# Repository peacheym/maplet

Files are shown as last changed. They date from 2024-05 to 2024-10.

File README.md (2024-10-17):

# Maplet

An ESP32 based eurorack module for libmapper connectivity.

## Why mappings in Eurorack?

Eurorack systems are excellent at making "generative music", where the system plays itself using sequencers, LFOs, clocks, and other modules. That said, there is lacking a method for "performative interaction" with Eurorack (asides from simply adjusting knobs directly on the system).

## Hardware

Maplet's front panel features a simple initial design.

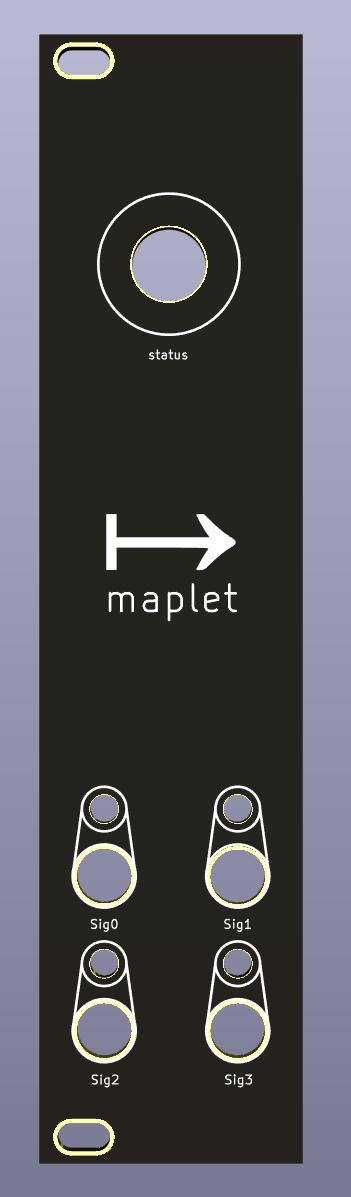
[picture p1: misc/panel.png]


## System Overview

The module uses an [UnexpectedMaker TinyPico](https://www.tinypico.com/) board based on the ESP32 chip as well as a MCP4728 digital-to-analog converter (DAC) as the main components.

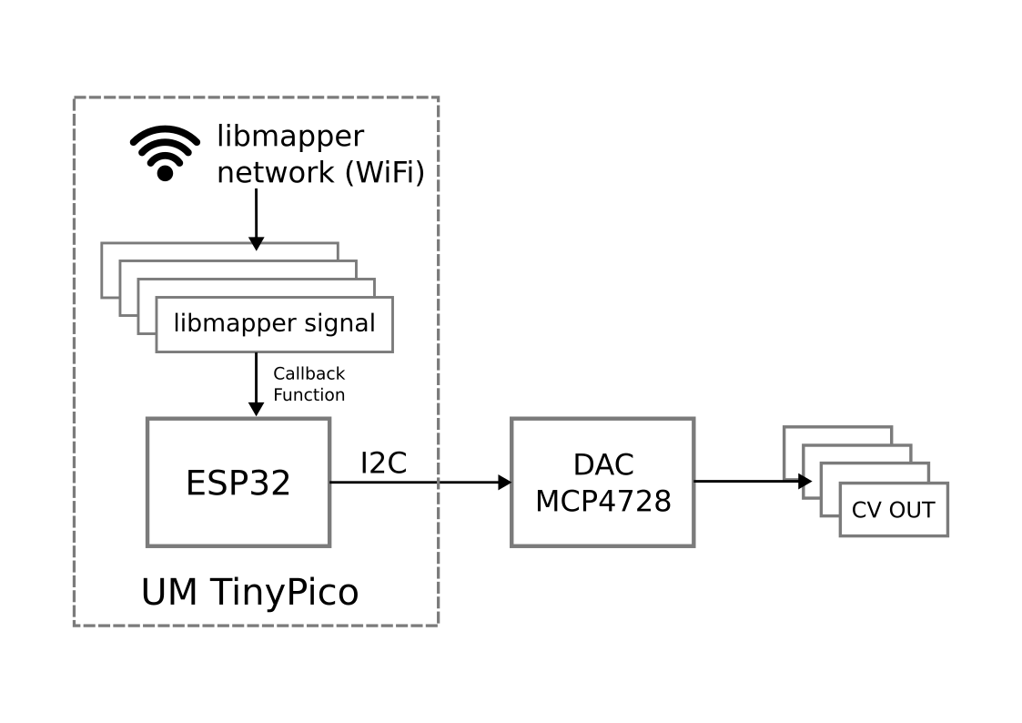
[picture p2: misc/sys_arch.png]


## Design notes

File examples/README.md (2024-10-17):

# Maplet Example | Mapping Hand Tracking to Eurorack Parameters

Maplet has many different use cases in the Eurorack ecosystem. Here's just one example!

pinch-demo

In this example, we show how to create a mapping between a machine-learning based hand-tracking system to parameters of a Eurorack macro-oscillator using the Maplet module.

## MediaPipe: Hands

[MediaPipe](https://github.com/google-ai-edge/mediapipe) is an open-source project maintained by Google that specializes on integrating machine learning with live-streaming data.

One such solution is MediaPipe: Hands that enables 3-dimensional multi-landmark hand-tracking using commodity web-camera. We've previously integrated a libmapper binding to MediaPipe hands ([avaliable here](https://github.com/peacheym/mp-hands-libmapper)) that exposes various hand-tracking landmarks as libmapper signals.

## Defining Mappings

With both the MediaPipe Hands software as well as the Maplet module up and running, we are able to begin creating mappings between them. Using a libmapper session manager such as [Webmapper](https://github.com/libmapper/webmapper/) or [umapper](https://github.com/libmapper/umapper), we can begin by creating a simple direct mapping between signals.

### Direct Mapping

For instance, creating a mapping between the `index-tip` signal and a channel on Maplet (which can be connected to a CV in for pitch-parameter on another eurorack module) results in a theremin type instrument, where the location of your finger-tip along the x-axis is directly mapped to the pitch of the oscilator.

### Convergent Mapping

Though direct mappings can be powerful tools for creating interactions with Digital Musical Insturments and other multimedia systems, there are other types of mapping topologies that libmapper also supports. For instance, a convergent mapping enables two (or more) outgoing signals to influence the value that is received by an incoming signal across the map. This is demonstrated in the main figure above, where both `index-tip` and `thumb-tip` signals are mapped to a channel of the Maplet module. 

```
y=(x$1-x$0).norm() * 4098;
```

Using a mapping-expression (which defines the exact relationship between data signals) we can measure the distance (in any number of avaliable dimensions) between finger-tips and use that result to emulate a pinch gesture. Thus, we can map the _amount of pinch_ to another CV controlled parameter (such as filter-cutoff for example) of a Eurorack module.

## Other examples.

While these initial examples show the basics of how to use the Maplet module as part of the libmapper workflow, we encourage all uers to try it out with their own systems. Feel free to get in touch with any questions or to show any interesting examples that you've come up with!

## Resources

- libmapper website | [link](https://libmapper.org)
- libmapper repo | [link](https://github.com/libmapper/libmapper)
- libmapper tutorials | [link](http://libmapper.github.io/tutorials/introduction.html)
- libmapper expression engine syntax guide | [link](https://github.com/libmapper/libmapper/blob/main/doc/expression_syntax.md)

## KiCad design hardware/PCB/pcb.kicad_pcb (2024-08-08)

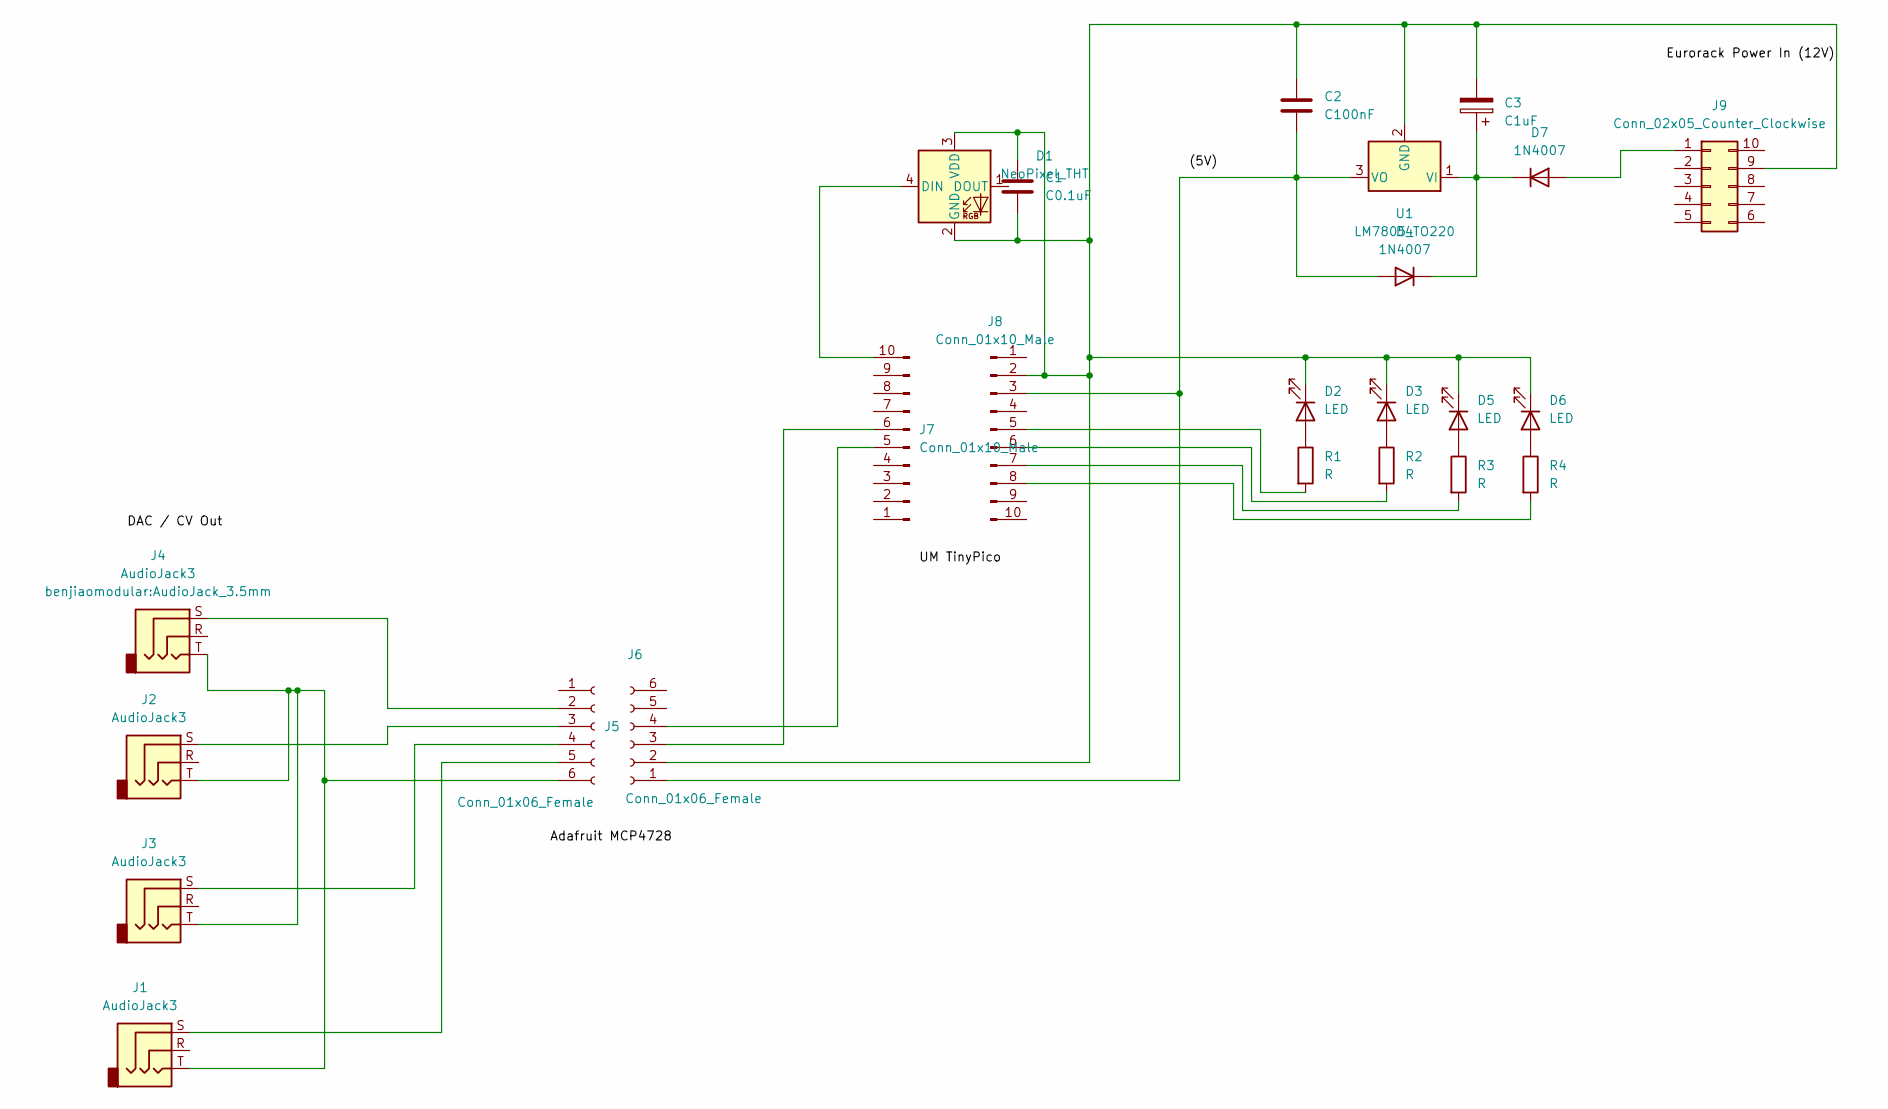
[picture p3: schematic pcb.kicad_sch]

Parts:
C1: C0.1uF; C_Rect_L4.0mm_W2.5mm_P2.50mm
C2: C100nF; C_Rect_L4.0mm_W2.5mm_P2.50mm
C3: C1uF; CP_Radial_D5.0mm_P2.50mm
D1: NeoPixel_THT; LED_D5.0mm-4_RGB_Staggered_Pins
D2, D3, D5, D6: LED; LED_D3.0mm
D4, D7: 1N4007; D_DO-41_SOD81_P10.16mm_Horizontal
J1, J2, J3, J4: AudioJack3; AudioJack_3.5mm
J5, J6: Conn_01x06_Female; PinSocket_1x06_P2.54mm_Vertical
J7, J8: Conn_01x10_Male; PinSocket_1x10_P2.54mm_Vertical
J9: Conn_02x05_Counter_Clockwise; IDC-Header_2x05_P2.54mm_Vertical
R1, R2, R3, R4: R; R_Axial_DIN0204_L3.6mm_D1.6mm_P2.54mm_Vertical
U1: LM7805_TO220; TO-220-3_Vertical

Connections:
unnamed: C1.1, C1.2, C2.1, C3.2, D1.2 (GND), D1.3 (VDD), D2.1 (K), D3.1 (K), D5.1 (K), D6.1 (K), J6.2, J8.2, J9.9, U1.2 (GND)
unnamed: C2.2, D4.2 (A), J6.1, J8.3, U1.3 (VO)
unnamed: C3.1, D4.1 (K), D7.1 (K), U1.1 (VI)
unnamed: D1.4 (DIN), J7.10
unnamed: D2.2 (A), R1.1
unnamed: D3.2 (A), R2.1
unnamed: D5.2 (A), R3.1
unnamed: D6.2 (A), R4.1
unnamed: D7.2 (A), J9.1
unnamed: J1.S, J5.5
unnamed: J2.S, J5.3
unnamed: J3.S, J5.4
unnamed: J4.S, J5.2
unnamed: J1.T, J2.T, J3.T, J4.T, J5.6
unnamed: J6.3, J7.6
unnamed: J6.4, J7.5
unnamed: J8.5, R1.2
unnamed: J8.6, R2.2
unnamed: J8.7, R3.2
unnamed: J8.8, R4.2

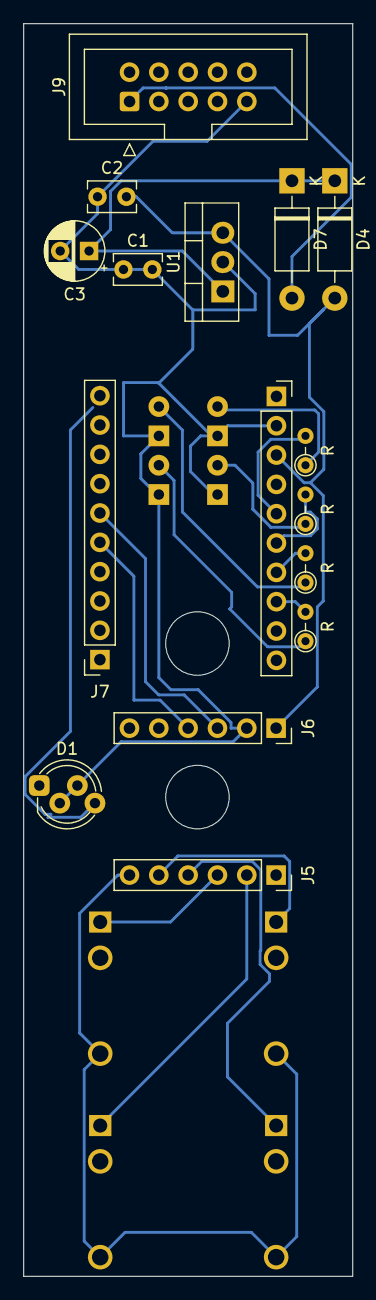
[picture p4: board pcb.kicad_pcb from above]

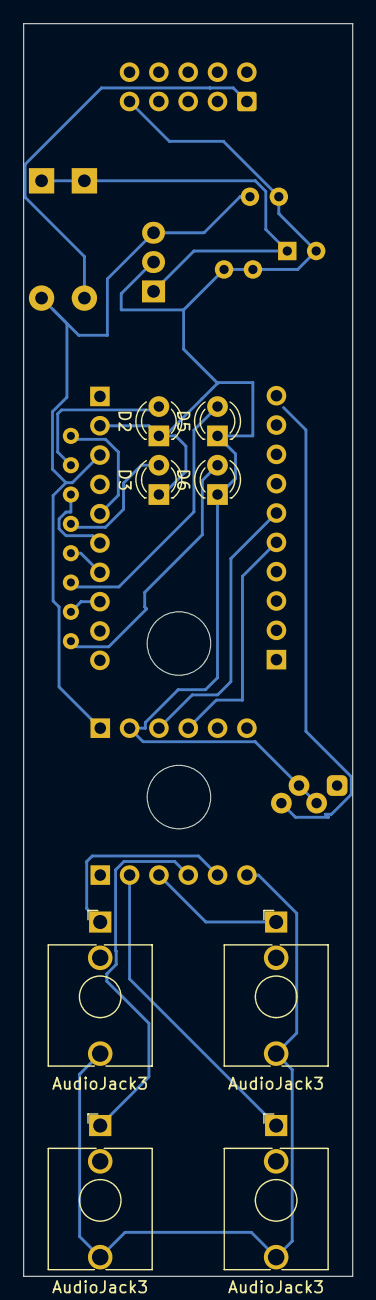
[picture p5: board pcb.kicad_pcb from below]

Board: 2 copper layers, 28.5 x 108.5 mm, 24 parts (8 on the bottom side), 20 nets.

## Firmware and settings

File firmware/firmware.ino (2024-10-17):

#include <Adafruit_NeoPixel.h>

#include <WiFi.h>
#include <mapper.h>
#include <Adafruit_MCP4728.h>
#include <Wire.h>

#ifdef __AVR__
  #include <avr/power.h>
#endif

Adafruit_NeoPixel pixels(1, 4, NEO_RGB + NEO_KHZ800);
#define DELAYVAL 500


// For disabling power saving
#include "esp_wifi.h"
Adafruit_MCP4728 mcp;

const char* ssid = "GemLab";
const char* password = "gemlabdal";

mpr_dev dev = 0;
mpr_sig inputSignal0 = 0;
mpr_sig inputSignal1 = 0;
mpr_sig inputSignal2 = 0;
mpr_sig inputSignal3 = 0;

float receivedValue = 0;
int DEBUG = 1;

void setup() {  

  int led_status_ind = 0;

  #if defined(__AVR_ATtiny85__) && (F_CPU == 16000000)
    clock_prescale_set(clock_div_1);
  #endif

  pixels.begin();
  pixels.setPixelColor(0, pixels.Color(155, 0, 0));
  pixels.show();

  WiFi.begin(ssid, password);
  Serial.begin(115200);
  
  // Disable WiFi power save (huge latency improvements)
  esp_wifi_set_ps(WIFI_PS_NONE);
  
  // Connect to WiFi
  while (WiFi.status() != WL_CONNECTED) {
    delay(500);
    Serial.print(".");
    if (led_status_ind==0){
      pixels.setPixelColor(0, pixels.Color(0,0,155));
      led_status_ind=1;
    }
    else{
      pixels.setPixelColor(0, pixels.Color(155, 0, 0));
      led_status_ind=0;
    }
    pixels.show();

  }
  Serial.println("Connected to WiFi");

//  pixels.setPixelColor(0, pixels.Color(0, 155, 0));
//  pixels.show();
//  pixels.setPixelColor(0, pixels.Color(0, 0, 155));
//  pixels.show();


  if(!mcp.begin(0x64)){
    Serial.println("Failed to find MCP4728");
    while(1){
      delay(10);
    }
  }

  Serial.println("Initialized DAC");


  // Initalize libmapper goodies
  float min_pw = 0.0f;
  float max_pw = 4095.0f;  

  dev = mpr_dev_new("Maplet", 0);

  Serial.println("Initialized libmapper device");

  inputSignal0 = mpr_sig_new(dev, MPR_DIR_IN, "channel1", 1, MPR_FLT, "V", &min_pw, &max_pw, 0, inputSignalHandler, MPR_SIG_UPDATE);
  inputSignal1 = mpr_sig_new(dev, MPR_DIR_IN, "channel2", 1, MPR_FLT, "V", &min_pw, &max_pw, 0, inputSignalHandler, MPR_SIG_UPDATE);           
  inputSignal2 = mpr_sig_new(dev, MPR_DIR_IN, "channel3", 1, MPR_FLT, "V", &min_pw, &max_pw, 0, inputSignalHandler, MPR_SIG_UPDATE);           
  inputSignal3 = mpr_sig_new(dev, MPR_DIR_IN, "channel4", 1, MPR_FLT, "V", &min_pw, &max_pw, 0, inputSignalHandler, MPR_SIG_UPDATE);           
           
  Serial.println("Initialized libmapper signals");

  for(int i=0; i<10; i++){
    mpr_dev_poll(dev, 500);

    if (led_status_ind==0){
      pixels.setPixelColor(0, pixels.Color(0,155,0));
      led_status_ind=1;
    }
    else{
      pixels.setPixelColor(0, pixels.Color(0, 0, 155));
      led_status_ind=0;
    }
    pixels.show();
  }

  Serial.println("Done Polling");

  pixels.setPixelColor(0, pixels.Color(0, 155, 0));
  pixels.show();

}

void loop() {  
  mpr_dev_poll(dev, 100);

//  int num_maps = mpr_obj_get_prop_as_int32(inputSignal0, MPR_PROP_NUM_MAPS_IN, NULL);
//
//  if(num_maps > 0){
//    pixels.setPixelColor(0, pixels.Color(0, 155, 67));
//  }
//  else{
//    pixels.setPixelColor(0, pixels.Color(255,0,0));
//  }
//  pixels.show();

}



void inputSignalHandler(mpr_sig sig, mpr_sig_evt evt, mpr_id inst, int length,
                        mpr_type type, const void* value, mpr_time time) {
    float val = *((float*)value);

    if(strcmp(mpr_obj_get_prop_as_str(sig, MPR_PROP_NAME, NULL), "channel1") == 0)
      mcp.setChannelValue(MCP4728_CHANNEL_A, (int)val);
    else if (strcmp(mpr_obj_get_prop_as_str(sig, MPR_PROP_NAME, NULL), "channel2") == 0)
        mcp.setChannelValue(MCP4728_CHANNEL_B, (int)val);
    else if (strcmp(mpr_obj_get_prop_as_str(sig, MPR_PROP_NAME, NULL), "channel3") == 0)
        mcp.setChannelValue(MCP4728_CHANNEL_C, (int)val);
    else if (strcmp(mpr_obj_get_prop_as_str(sig, MPR_PROP_NAME, NULL), "channel4") == 0)
        mcp.setChannelValue(MCP4728_CHANNEL_D, (int)val);
    else Serial.println("Error with signal names");
    
}

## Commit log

2024-05-03 Add initial kicad files. Very much an experimental WIP
    [hardware.kicad_pcb, hardware.kicad_sch]
2024-07-31 Add second KiCad project for PCB
    [FrontPanel.kicad_pcb, FrontPanel.kicad_sch, hardware.kicad_pcb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]
2024-08-08 Add latest KICAD updates.
    [FrontPanel.kicad_pcb, pcb.kicad_pcb, pcb.kicad_sch]
